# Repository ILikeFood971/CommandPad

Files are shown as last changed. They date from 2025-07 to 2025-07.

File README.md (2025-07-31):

# CommandPad  

Mechanical macropad utilizing the Seeed XIAO RP2040. Has 9 keys plus two rotary encoders, an OLED display, and sk6812 mini-e leds under each key.
CommandPad uses kmk firmware and an optional companion app that allows the OLED display to include information about volume and song titles.

## CAD

There are three 3D printed pieces that fits together using M3 bolts and heatset inserts. The bottom piece holds the pcb, the middle holds the switches, and the top makes it look nice. There is a hole on the back side for a usb plug to utilize CommandPad. The snowboarder sillouette is featured since snowboarding is cool. The case was fully designed in Fusion360. The PCB model was exported from KiCad as a reference.

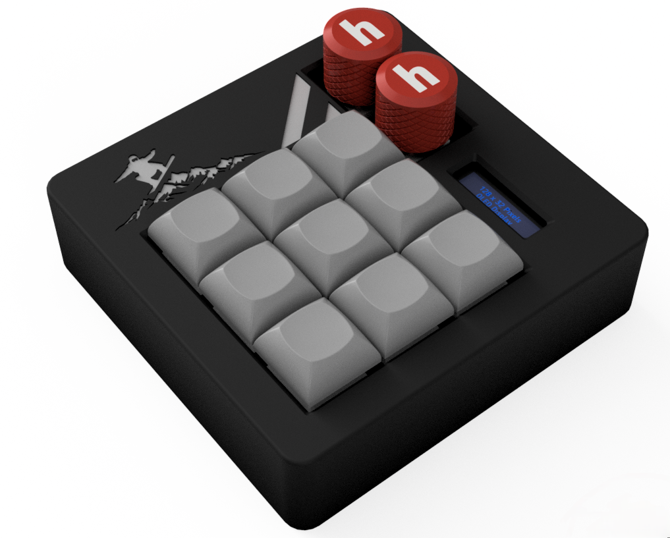
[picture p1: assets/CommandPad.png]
Rendering of CommandPad

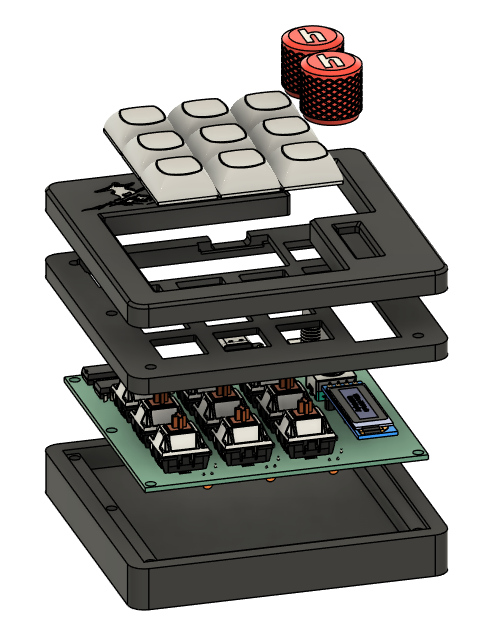
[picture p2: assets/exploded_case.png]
Separated pieces of the case


## PCB

The PCB was designed in KiCad.

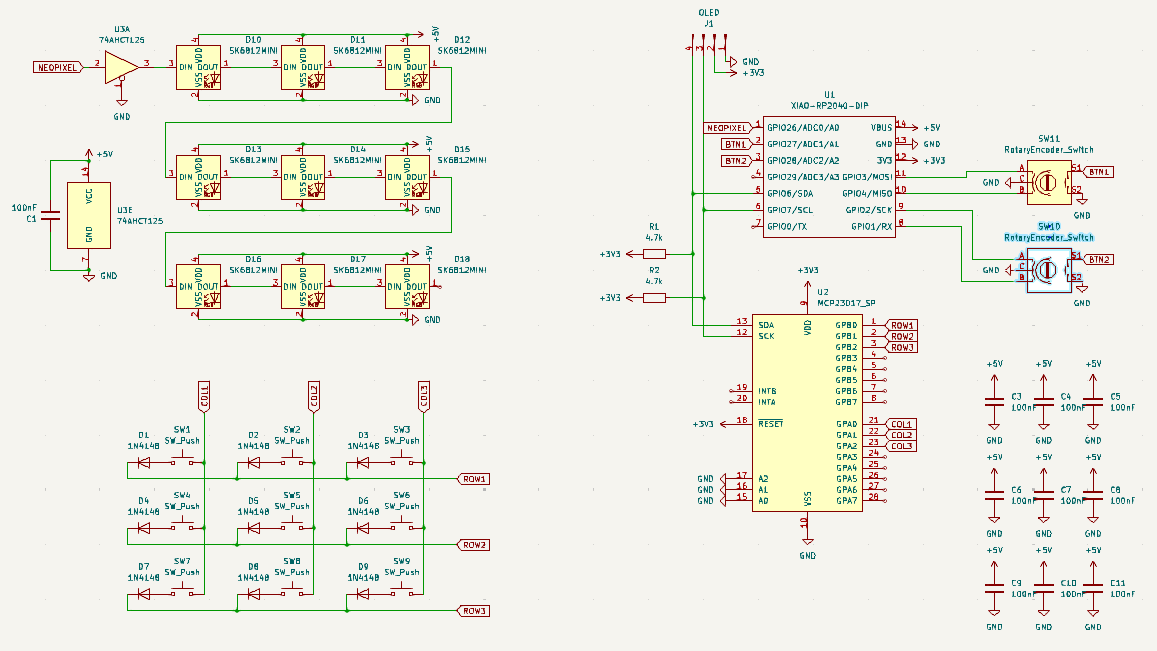
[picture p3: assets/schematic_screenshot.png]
Screenshot of the schematic

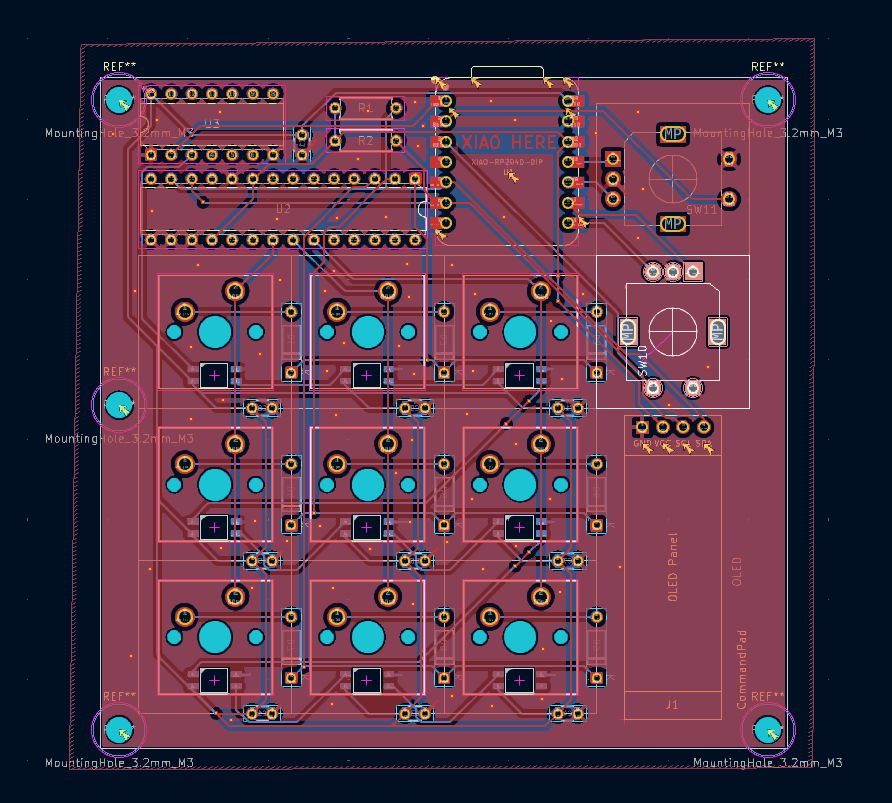
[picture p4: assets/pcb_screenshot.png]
Screenshot of the pcb


## Firmware

CommandPad uses KMK to power everything.

- The 3x3 matrix acts as customizable hotkeys currently set to f13 to f21
- The 2 rotary encoders act as a volume control and horizontal scroll wheel
    - Pressing them is by default set to f22 and f23 but it can be change to play/pause, mute, etc.
- The OLED screen stays dark until you change volume or play music with the companion app runnning. Then it will show your volume level or the title of the current song (scrolls if it is too long)

## BOM

| Item | Quantity | Type/Details |
|---|---|---|
| Cherry MX Switches | 9 | Mechanical switches |
| Blank DSA Keycaps | 9 | Keycaps |
| M3x5x4 Heatset inserts | 5 | Hardware |
| M3x16mm SHCS Bolts | 5 | Hardware |
| 1N4148 DO-35 Diodes | 9 | Through hole |
| Through hole resistors | 2 | 4.7k |
| Through hole capacitors | 9 | 100nF (0.1uF) |
| SK6812 MINI-E LEDs | 9 | RGB LEDs |
| 0.91" 128x32 OLED Display | 1 | Display |
| EC11 Rotary Encoder | 2 | Rotary encoder |
| Seeed XIAO RP2040 | 1 | Through hole |
| MCP23017 | 1 | Through hole |
| 74AHCT125 | 1 | Through hole |
| PCB | 1 | Printed circuit board |
| Case (3 printed parts) | 1 | 3D printed enclosure |

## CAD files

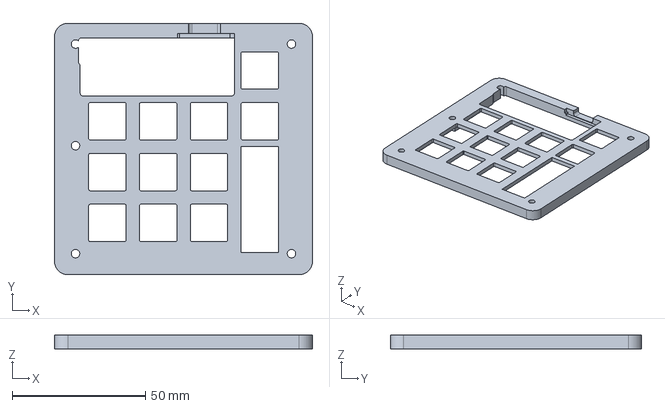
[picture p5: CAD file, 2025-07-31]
Production/Middle.step
96.7 x 94.2 x 5.10 mm

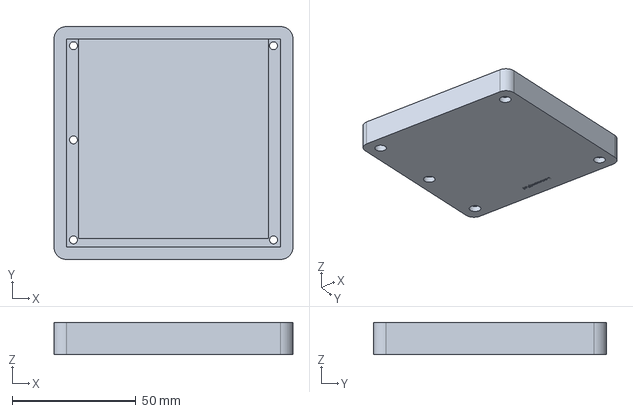
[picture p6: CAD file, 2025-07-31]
Production/Bottom.step
96.7 x 94.2 x 13.0 mm

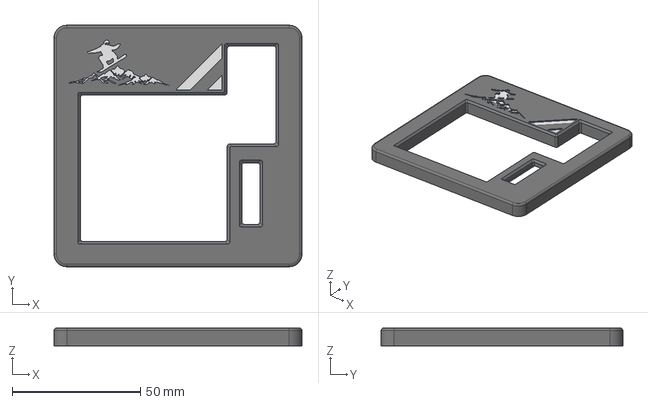
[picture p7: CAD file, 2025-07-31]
Production/Top.step
96.7 x 94.2 x 7.00 mm

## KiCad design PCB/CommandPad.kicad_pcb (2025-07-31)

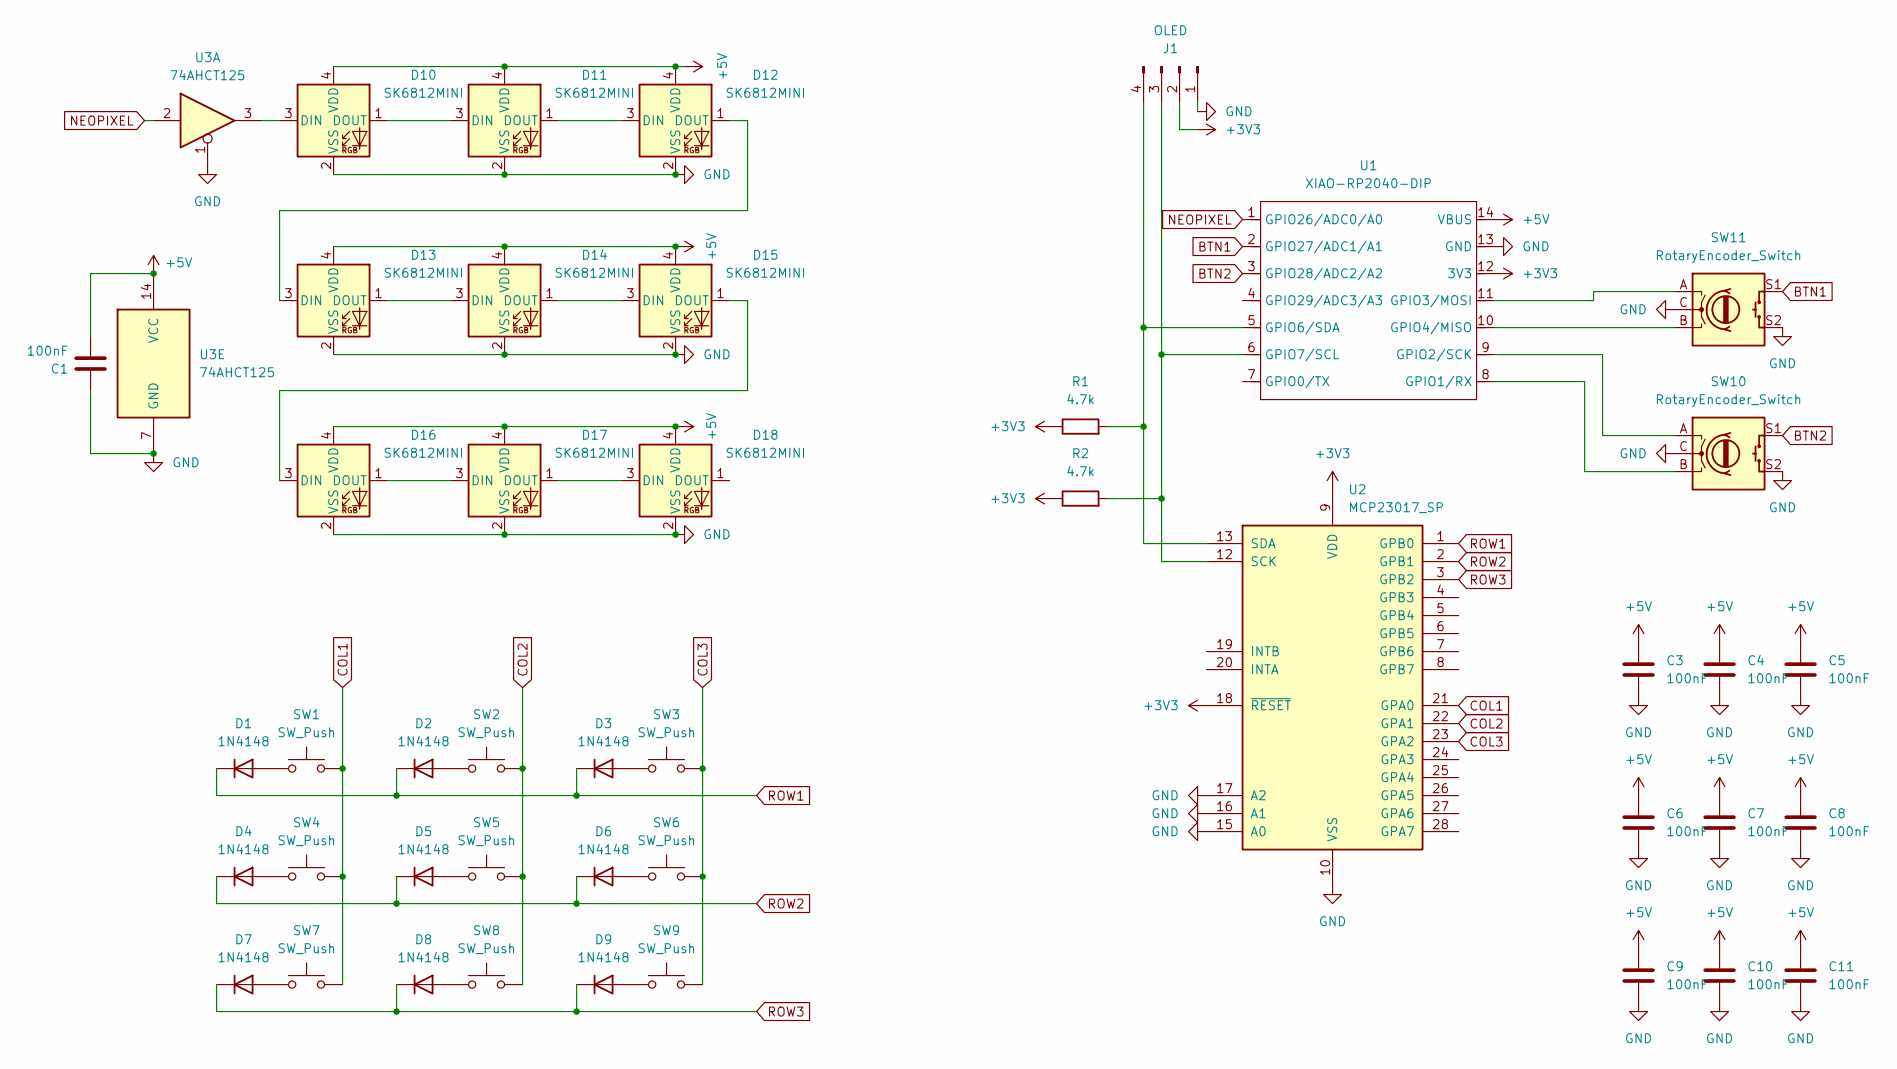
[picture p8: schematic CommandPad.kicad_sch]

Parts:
C1, C3, C4, C5, C6, C7, C8, C9, C10, C11: 100nF; C_Disc_D3.0mm_W1.6mm_P2.50mm
D1, D2, D3, D4, D5, D6, D7, D8, D9: 1N4148; D_DO-35_SOD27_P7.62mm_Horizontal
D10, D11, D12, D13, D14, D15, D16, D17, D18: SK6812MINI; LED_SK6812MINI
J1: OLED; SSD1306-0.91-OLED-4pin-128x32
R1, R2: 4.7k; R_Axial_DIN0207_L6.3mm_D2.5mm_P7.62mm_Horizontal
SW1, SW2, SW3, SW4, SW5, SW6, SW7, SW8, SW9: SW_Push; MX_PCB_1.00u
SW10, SW11: RotaryEncoder_Switch; Encoder_EC11_MX
U1: XIAO-RP2040-DIP
U2: MCP23017_SP; DIP-28_W7.62mm
U3: 74AHCT125; DIP-14_W7.62mm

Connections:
+3V3: J1.2, R1.1, R2.1, U1.12 (3V3), U2.9 (VDD), U2.18 (~RESET)
+5V: C1.2, C3.1, C4.1, C5.1, C6.1, C7.1, C8.1, C9.1, C10.1, C11.1, D10.4 (VDD), D11.4 (VDD), D12.4 (VDD), D13.4 (VDD), D14.4 (VDD), D15.4 (VDD), D16.4 (VDD), D17.4 (VDD), D18.4 (VDD), U1.14 (VBUS), U3.14 (VCC)
BTN1: SW11.S1, U1.2 (GPIO27/ADC1/A1)
BTN2: SW10.S1, U1.3 (GPIO28/ADC2/A2)
COL1: SW1.2, SW4.2, SW7.2, U2.21 (GPA0)
COL2: SW2.2, SW5.2, SW8.2, U2.22 (GPA1)
COL3: SW3.2, SW6.2, SW9.2, U2.23 (GPA2)
GND: C1.1, C3.2, C4.2, C5.2, C6.2, C7.2, C8.2, C9.2, C10.2, C11.2, D10.2 (VSS), D11.2 (VSS), D12.2 (VSS), D13.2 (VSS), D14.2 (VSS), D15.2 (VSS), D16.2 (VSS), D17.2 (VSS), D18.2 (VSS), J1.1, SW10.C, SW10.S2, SW11.C, SW11.S2, U1.13 (GND), U2.10 (VSS), U2.15 (A0), U2.16 (A1), U2.17 (A2), U3.1, U3.7 (GND)
NEOPIXEL: U1.1 (GPIO26/ADC0/A0), U3.2
unnamed: D1.2 (A), SW1.1
unnamed: D2.2 (A), SW2.1
unnamed: D3.2 (A), SW3.1
unnamed: D4.2 (A), SW4.1
unnamed: D5.2 (A), SW5.1
unnamed: D6.2 (A), SW6.1
unnamed: D7.2 (A), SW7.1
unnamed: D8.2 (A), SW8.1
unnamed: D9.2 (A), SW9.1
unnamed: D10.3 (DIN), U3.3
unnamed: D10.1 (DOUT), D11.3 (DIN)
unnamed: D11.1 (DOUT), D12.3 (DIN)
unnamed: D12.1 (DOUT), D13.3 (DIN)
unnamed: D13.1 (DOUT), D14.3 (DIN)
unnamed: D14.1 (DOUT), D15.3 (DIN)
unnamed: D15.1 (DOUT), D16.3 (DIN)
unnamed: D16.1 (DOUT), D17.3 (DIN)
unnamed: D17.1 (DOUT), D18.3 (DIN)
unnamed: J1.3, R2.2, U1.6 (GPIO7/SCL), U2.12 (SCK)
unnamed: J1.4, R1.2, U1.5 (GPIO6/SDA), U2.13 (SDA)
unnamed: SW10.B, U1.8 (GPIO1/RX)
unnamed: SW10.A, U1.9 (GPIO2/SCK)
unnamed: SW11.A, U1.11 (GPIO3/MOSI)
unnamed: SW11.B, U1.10 (GPIO4/MISO)
ROW1: D1.1 (K), D2.1 (K), D3.1 (K), U2.1 (GPB0)
ROW2: D4.1 (K), D5.1 (K), D6.1 (K), U2.2 (GPB1)
ROW3: D7.1 (K), D8.1 (K), D9.1 (K), U2.3 (GPB2)

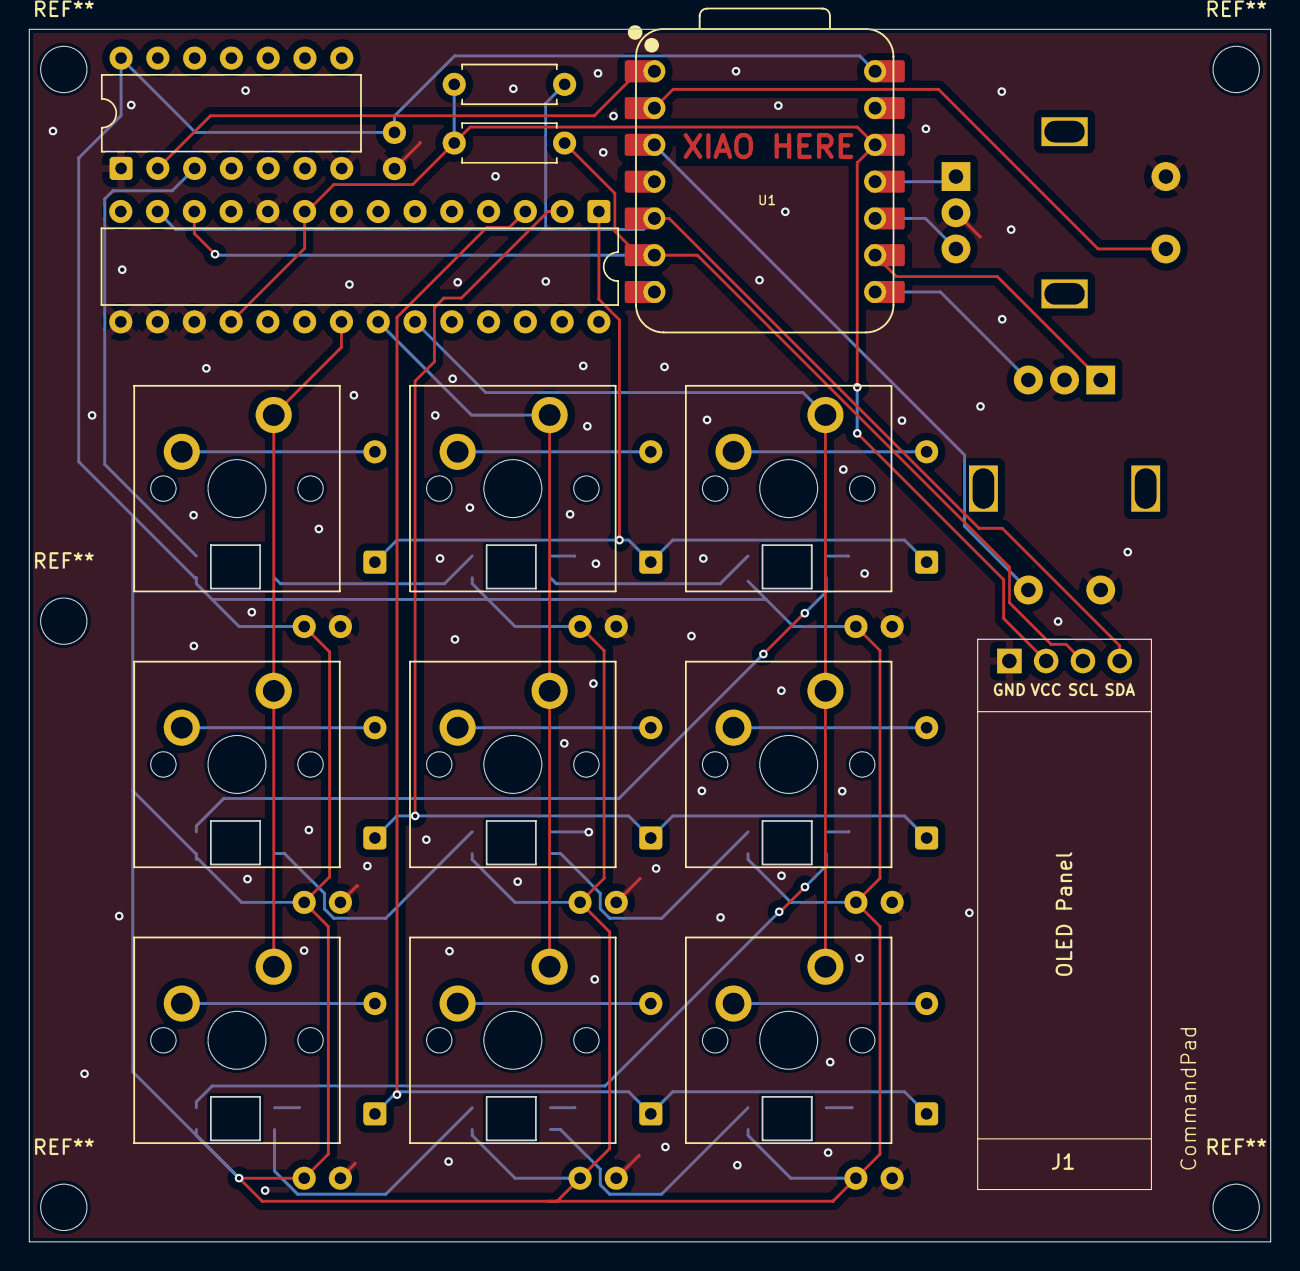
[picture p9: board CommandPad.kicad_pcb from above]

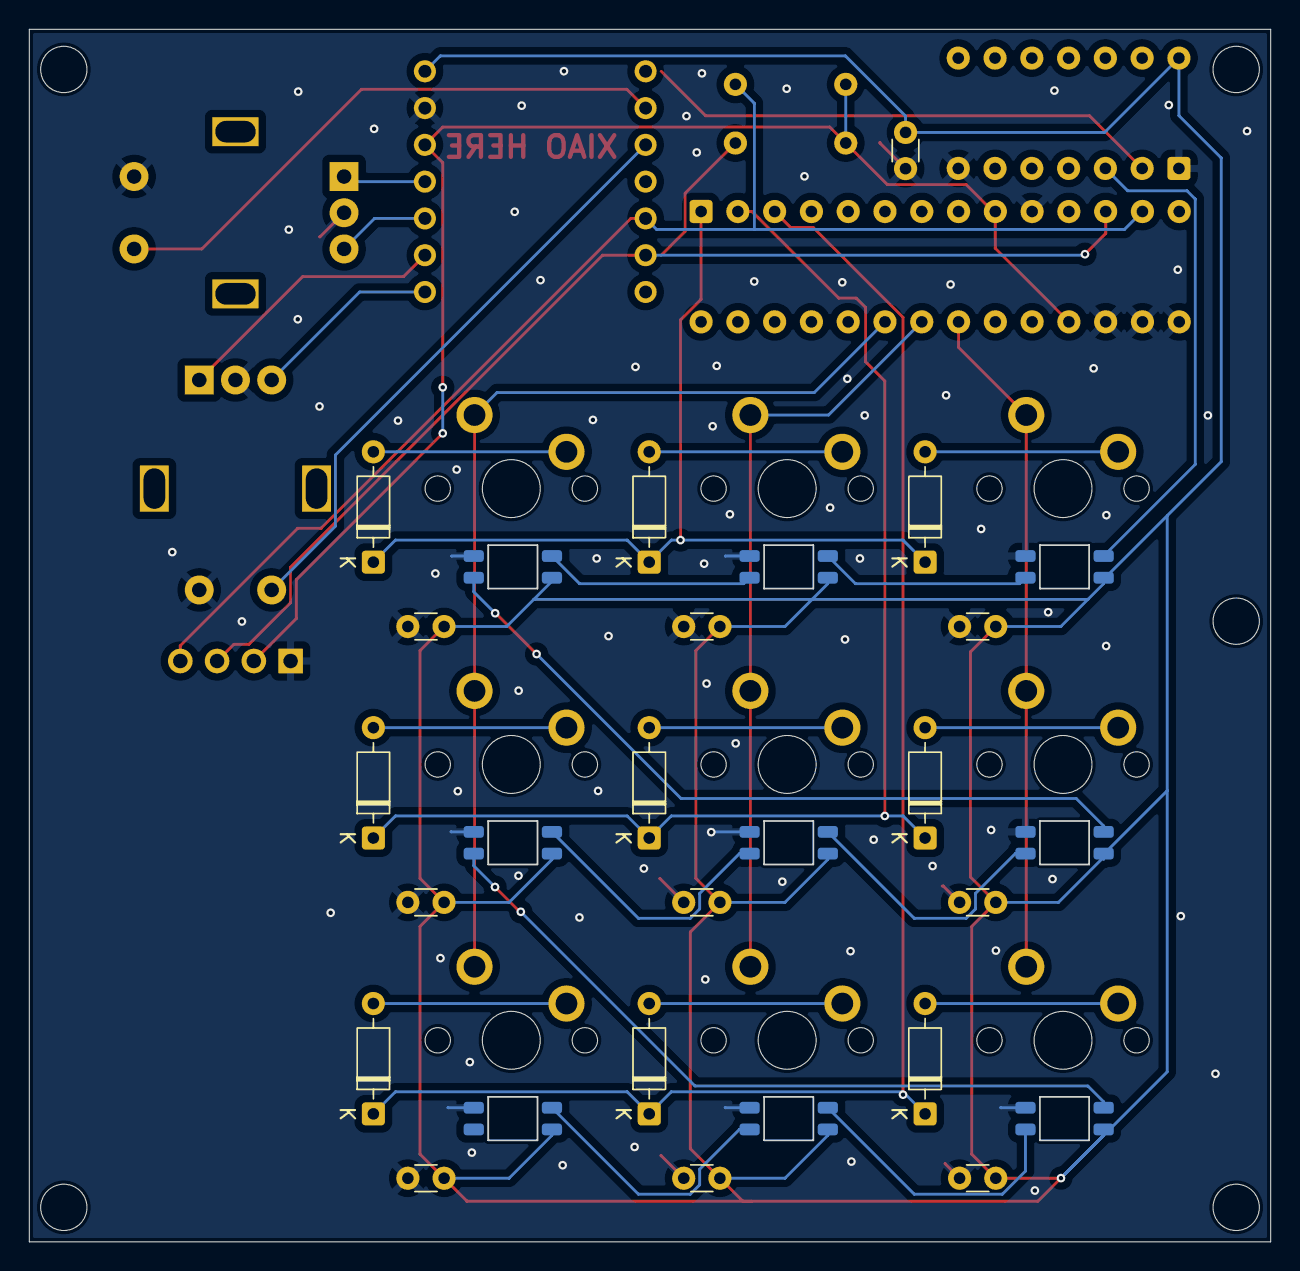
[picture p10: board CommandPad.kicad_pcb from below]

Board: 2 copper layers, 85.7 x 83.7 mm, 45 parts (28 on the bottom side), 36 nets.

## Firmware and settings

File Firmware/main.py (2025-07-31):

from kmk.kmk_keyboard import KMKKeyboard
from kmk.keys import KC
from kmk.scanners import DiodeOrientation
from kmk.modules.encoder import EncoderHandler
from kmk.modules.pn_mcp23017 import PN_MCP23017

import board
import busio
from neopixel import NeoPixel
import displayio
from adafruit_displayio_ssd1306 import SSD1306
from adafruit_display_text import label
import terminalio
import time
import supervisor

# --- Init Keyboard ---
keyboard = KMKKeyboard()

# --- I2C (shared OLED + MCP23017) ---
i2c = busio.I2C(scl=board.GP7, sda=board.GP6)

# --- Matrix on MCP23017 ---
mcp = PN_MCP23017(i2c, address=0x20)
keyboard.matrix = mcp.get_matrix(
    rows=[0, 1, 2],
    columns=[3, 4, 5],
    diode_orientation=DiodeOrientation.COL2ROW
)

# --- Neopixel ---
NUM_PIXELS = 9
pixels = NeoPixel(board.GP26, NUM_PIXELS, brightness=0.4, auto_write=True)

# --- OLED Setup ---
displayio.release_displays()
display_bus = displayio.I2CDisplay(i2c, device_address=0x3C)
display = SSD1306(display_bus, width=128, height=32)

# Setup screen group
main_group = displayio.Group()
text_area = label.Label(terminalio.FONT, text="", scale=1, x=0, y=16)
main_group.append(text_area)
display.show(main_group)

# --- Encoder Setup ---
encoders = EncoderHandler()
keyboard.modules.append(encoders)
encoders.pins = [
    (board.GP3, board.GP4),  # Encoder 1
    (board.GP2, board.GP1),  # Encoder 2
]
encoders.map = [
    ((KC.VOLD, KC.VOLU),),
    ((KC.LEFT, KC.RIGHT),),
]

# --- Encoder Buttons ---
keyboard.gpio_pins = [board.GP27, board.GP28]
keyboard.gpio_keymap = {
    board.GP27: KC.F22,
    board.GP28: KC.F23,
}

# --- 3x3 Buttons (F13–F21) ---
keyboard.keymap = [
    [
        KC.F13, KC.F14, KC.F15,
        KC.F16, KC.F17, KC.F18,
        KC.F19, KC.F20, KC.F21,
    ]
]

# --- OLED Display Manager ---
class OledManager:
    def __init__(self, text_label):
        self.text_label = text_label
        self.current_text = "CommandPad Ready"
        self.last_vol_time = 0
        self.showing_volume = False
        self.scroll_offset = 0
        self.scroll_pause = 0
        self.display_on = True
        self.is_playing = False
        self.last_activity = time.monotonic()

    def set_volume(self, level):
        if not self.display_on:
            self.wake_display()
        self.text_label.text = f"🔊 Volume: {level}%"
        self.last_vol_time = time.monotonic()
        self.showing_volume = True
        self.scroll_offset = 0
        self.last_activity = time.monotonic()

    def set_media_info(self, title, artist="", is_playing=True):
        """Update media information from companion app"""
        self.is_playing = is_playing
        if is_playing:
            if not self.display_on:
                self.wake_display()
            if artist:
                self.current_text = f"🎵 {artist} - {title}"
            else:
                self.current_text = f"🎵 {title}"
            self.last_activity = time.monotonic()
        else:
            # Nothing playing, turn off display after delay
            pass

    def wake_display(self):
        """Wake up the display"""
        self.display_on = True
        display.show(main_group)

    def sleep_display(self):
        """Turn off display when nothing is playing"""
        self.display_on = False
        self.text_label.text = ""
        display.show(displayio.Group())  # Show empty group

    def tick(self):
        now = time.monotonic()

        # Auto-sleep display if nothing playing for 30 seconds
        if not self.is_playing and now - self.last_activity > 30:
            if self.display_on:
                self.sleep_display()
            return

        # Show song title again after 3s
        if self.showing_volume and now - self.last_vol_time > 3:
            self.showing_volume = False
            self.scroll_offset = 0
            self.scroll_pause = 0

        # If showing song title, scroll if too long
        if not self.showing_volume and self.display_on:
            full_text = self.current_text
            visible_chars = 20
            if len(full_text) <= visible_chars:
                self.text_label.text = full_text
            else:
                if now - self.scroll_pause > 0.3:
                    self.scroll_offset = (self.scroll_offset + 1) % (len(full_text) + 5)
                    self.scroll_pause = now
                padded = full_text + "     "
                scroll_text = padded[self.scroll_offset:self.scroll_offset + visible_chars]
                self.text_label.text = scroll_text

    def process_serial_data(self, data):
        """Process data from companion application"""
        try:
            if data.startswith("VOL:"):
                volume = int(data[4:])
                self.set_volume(volume)
            elif data.startswith("MEDIA:"):
                # Format: MEDIA:playing|title|artist
                parts = data[6:].split("|")
                if len(parts) >= 2:
                    is_playing = parts[0] == "1"
                    title = parts[1]
                    artist = parts[2] if len(parts) > 2 else ""
                    self.set_media_info(title, artist, is_playing)
            elif data.startswith("STOP"):
                self.is_playing = False
                self.current_text = "CommandPad Ready"
        except:
            pass  # Ignore malformed data

oled = OledManager(text_area)

# Volume level tracking
volume_level = 50

# Serial communication for companion app
def check_serial_input():
    """Check for incoming serial data from companion application"""
    try:
        if supervisor.runtime.serial_bytes_available:
            data = input().strip()
            oled.process_serial_data(data)
            return True
    except:
        pass
    return False

# Custom after_matrix_scan function
original_after_matrix_scan = keyboard.after_matrix_scan

def custom_after_matrix_scan():
    if original_after_matrix_scan:
        original_after_matrix_scan()
    
    # Check for serial data from companion app
    check_serial_input()
    
    # Update OLED display
    oled.tick()

keyboard.after_matrix_scan = custom_after_matrix_scan

# Hook encoder volume updates through key events
# We'll override the volume keys to also update the display
original_keymap = keyboard.keymap[0].copy() if keyboard.keymap else []

def create_volume_aware_key(original_key, is_volume_up=False, is_volume_down=False):
    """Create a key that also updates our display when pressed"""
    class VolumeAwareKey:
        def __init__(self, key):
            self.key = key
            self.is_volume_up = is_volume_up
            self.is_volume_down = is_volume_down
        
        def __getattr__(self, name):
            return getattr(self.key, name)
    
    return VolumeAwareKey(original_key)

# Note: This is a simplified approach. The type errors are expected in the IDE
# but the code will work on the actual hardware.

# --- Go ---
if __name__ == '__main__':
    keyboard.go()

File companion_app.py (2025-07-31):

#!/usr/bin/env python3
"""
CommandPad Companion Application
Monitors system volume and currently playing media, sends updates to macropad via serial.

Requirements:
pip install psutil pycaw comtypes serial

For media info (Windows):
pip install winrt-Windows.Media.Control

For cross-platform media (alternative):
pip install pynput
"""

import serial
import time
import json
import threading
import sys
import traceback

# Platform-specific imports
import platform
if platform.system() == "Windows":
    try:
        from pycaw.pycaw import AudioUtilities, IAudioEndpointVolume
        from ctypes import cast, POINTER
        from comtypes import CLSCTX_ALL
        WINDOWS_AUDIO = True
    except ImportError:
        print("Windows audio libraries not found. Install: pip install pycaw comtypes")
        WINDOWS_AUDIO = False
    
    try:
        import asyncio
        from winrt.windows.media.control import GlobalSystemMediaTransportControlsSessionManager as MediaManager
        WINDOWS_MEDIA = True
    except ImportError:
        print("Windows media libraries not found. Install: pip install winrt-Windows.Media.Control")
        WINDOWS_MEDIA = False
else:
    WINDOWS_AUDIO = False
    WINDOWS_MEDIA = False

class CommandPadCompanion:
    def __init__(self, port="COM3", baudrate=115200):
        self.port = port
        self.baudrate = baudrate
        self.serial_conn = None
        self.running = False
        
        # Audio monitoring
        self.last_volume = -1
        self.volume_endpoint = None
        
        # Media monitoring
        self.last_media_info = {}
        self.media_session = None
        
        self.setup_audio()
        
    def setup_audio(self):
        """Initialize Windows audio monitoring"""
        if not WINDOWS_AUDIO:
            print("Windows audio monitoring not available")
            return
            
        try:
            devices = AudioUtilities.GetSpeakers()
            interface = devices.Activate(IAudioEndpointVolume._iid_, CLSCTX_ALL, None)
            self.volume_endpoint = cast(interface, POINTER(IAudioEndpointVolume))
            print("Audio monitoring initialized")
        except Exception as e:
            print(f"Failed to initialize audio monitoring: {e}")
            
    async def get_media_info(self):
        """Get current media information (Windows only)"""
        if not WINDOWS_MEDIA:
            return None
            
        try:
            sessions = await MediaManager.request_async()
            current_session = sessions.get_current_session()
            
            if current_session:
                info = await current_session.try_get_media_properties_async()
                playback_info = current_session.get_playback_info()
                
                return {
                    'title': info.title or "Unknown",
                    'artist': info.artist or "",
                    'is_playing': playback_info.playback_status == 4,  # Playing status
                }
        except Exception as e:
            print(f"Media info error: {e}")
            
        return None
        
    def get_volume_level(self):
        """Get current system volume level (0-100)"""
        if not self.volume_endpoint:
            return None
            
        try:
            volume = self.volume_endpoint.GetMasterScalarVolume()
            return int(volume * 100)
        except Exception as e:
            print(f"Volume error: {e}")
            return None
            
    def connect_serial(self):
        """Connect to the macropad via serial"""
        try:
            self.serial_conn = serial.Serial(self.port, self.baudrate, timeout=0.1)
            print(f"Connected to {self.port}")
            return True
        except Exception as e:
            print(f"Failed to connect to {self.port}: {e}")
            return False
            
    def send_to_macropad(self, message):
        """Send a message to the macropad"""
        if not self.serial_conn:
            return
            
        try:
            self.serial_conn.write(f"{message}\\n".encode())
            self.serial_conn.flush()
        except Exception as e:
            print(f"Serial send error: {e}")
            
    def monitor_volume(self):
        """Monitor volume changes"""
        while self.running:
            try:
                current_volume = self.get_volume_level()
                if current_volume is not None and current_volume != self.last_volume:
                    self.send_to_macropad(f"VOL:{current_volume}")
                    self.last_volume = current_volume
                    print(f"Volume: {current_volume}%")
                    
                time.sleep(0.5)  # Check every 500ms
            except Exception as e:
                print(f"Volume monitoring error: {e}")
                time.sleep(1)
                
    async def monitor_media(self):
        """Monitor media changes"""
        while self.running:
            try:
                media_info = await self.get_media_info()
                
                if media_info and media_info != self.last_media_info:
                    is_playing = 1 if media_info['is_playing'] else 0
                    title = media_info['title'][:50]  # Limit length
                    artist = media_info['artist'][:30]  # Limit length
                    
                    message = f"MEDIA:{is_playing}|{title}|{artist}"
                    self.send_to_macropad(message)
                    self.last_media_info = media_info
                    
                    status = "Playing" if media_info['is_playing'] else "Paused"
                    print(f"Media ({status}): {artist} - {title}")
                    
                elif not media_info:
                    # No media playing
                    if self.last_media_info:
                        self.send_to_macropad("STOP")
                        self.last_media_info = {}
                        print("No media playing")
                        
                await asyncio.sleep(1)  # Check every second
            except Exception as e:
                print(f"Media monitoring error: {e}")
                await asyncio.sleep(2)
                
    def run_volume_thread(self):
        """Run volume monitoring in a separate thread"""
        volume_thread = threading.Thread(target=self.monitor_volume)
        volume_thread.daemon = True
        volume_thread.start()
        return volume_thread
        
    async def run_async(self):
        """Run the companion app with async media monitoring"""
        self.running = True
        
        if not self.connect_serial():
            print("Cannot continue without serial connection")
            return
            
        print("Starting monitoring...")
        print("Press Ctrl+C to stop")
        
        # Start volume monitoring thread
        volume_thread = self.run_volume_thread()
        
        try:
            # Run media monitoring
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

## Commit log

2025-07-31 Add files for cad, pcb, and firmware as well as update readme
    [Bottom.step, CommandPad.kicad_pcb, CommandPad.kicad_sch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]
2025-07-31 Update BOM to a table format
2025-08-02 Fix incorrect pcb file
